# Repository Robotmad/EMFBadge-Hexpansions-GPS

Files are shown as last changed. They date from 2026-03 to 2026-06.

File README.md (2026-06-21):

# 📡 GPS Hexpansion for Tildagon Badge

A GPS Hexpansion module and basic software implementation for the Tildagon badge.

This project provides a working foundation for adding location awareness to badge applications — including hardware integration, UART communication, and NMEA parsing.

Designed for experimentation, hacking, and building more advanced location-based features.

They are available to buy here: https://themachineshop.uk/products/gps-hexpansion/

---

## ✨ Overview

This repository contains:

* ⚙️ Hardware files built in KiCAD
* 📡 UART-based communication with a GPS module
* 🧠 Basic NMEA parsing (RMC / GGA)
* 🖥️ Minimal software to extract and use position data
* 📷 Images of the board

It’s intended as a **starting point** for developing GPS-enabled badge apps.

---

## 🖼️ Hardware

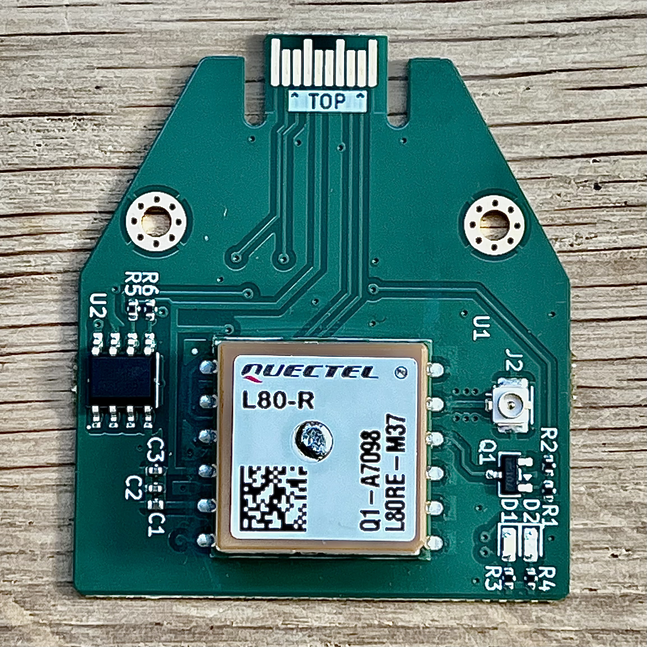
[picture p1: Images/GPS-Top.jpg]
GPS Hexpansion Top

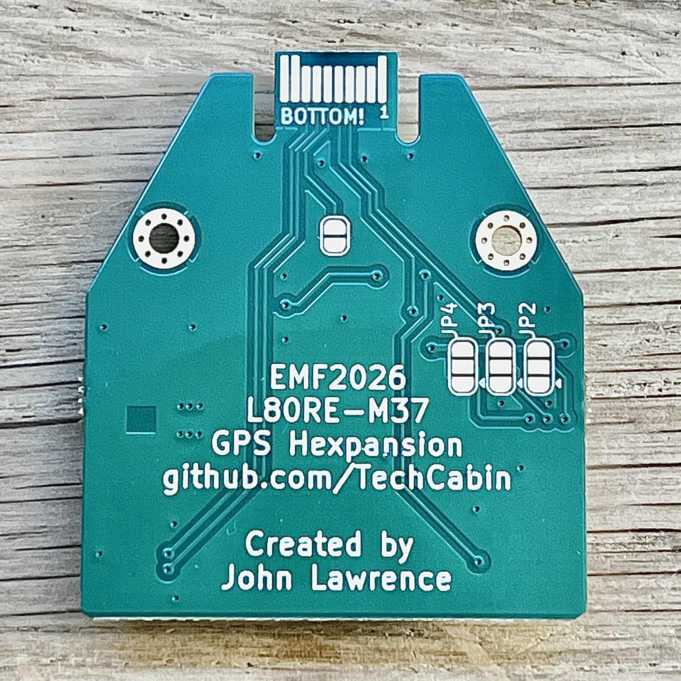
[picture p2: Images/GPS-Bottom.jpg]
GPS Hexpansion Bottom

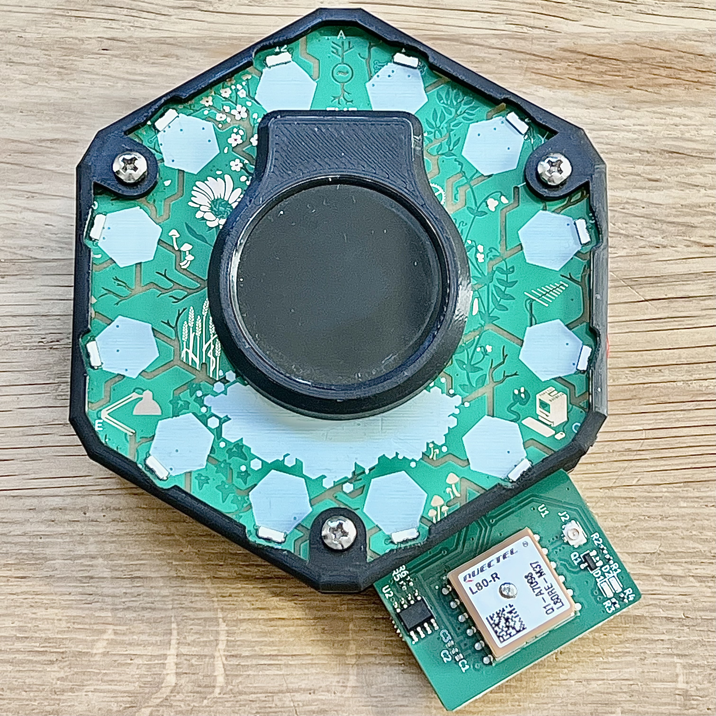
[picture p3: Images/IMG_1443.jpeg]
Badge with Hexpansion

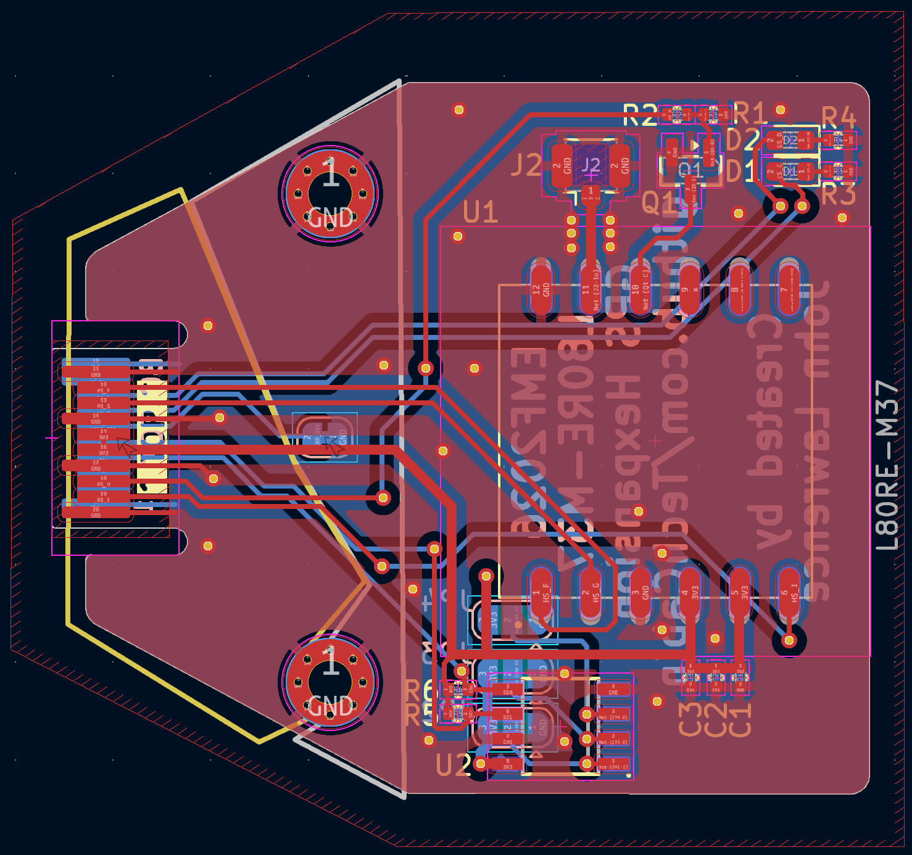
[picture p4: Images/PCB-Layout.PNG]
Hexpansion Layout

---

## 🔌 Hardware Details

* Compatible with the EMF2026 Tildagon Badge
* L80RE-M37 GPS module with built-in patch antenna
* External antenna connector with automatic switch over
* M24C16-RMN6TP EEPROM
* Red and Yellow LEDs

## ⚙️ Software

The software demonstrates:

* Reading serial data from the GPS module
* Parsing NMEA sentences (`$GNRMC`, `$GPGGA`)
* Extracting:

  * Latitude
  * Longitude
  * Fix status

This provides a clean base layer for any GPS-driven feature.

---

## 🧠 How It Works

1. GPS module outputs NMEA strings over UART
2. Badge reads serial stream
3. Valid sentences are identified
4. Data is parsed into usable values
5. Position data becomes available to your application
6. LED D1 is lit when there is a valid fix
---

## 🚀 Getting Started

```bash
git clone https://github.com/TechCabin/EMFBadge-Hexpansions-GPS.git
```

1. Flash MicroPython to your badge via mpremote
2. Copy project files to the device
3. Connect the GPS module via UART
4. Power on the badge
5. Wait for a valid GPS fix

---

## ⚠️ Notes

* Outdoor use significantly improves performance
* First fix can take 30–60 seconds (cold start)

---

## 🛣️ TODO

* [ ] Improve NMEA parser robustness
* [ ] Add support for additional sentence types
* [ ] Abstract GPS into a reusable module/class
* [ ] Add example applications (mapping, tracking, etc.)
* [ ] Add signal quality / satellite info

---

## 🔧 Future Ideas

* Real-time mapping
* Etch-a-Sktech app
* Geofencing features
* Time synchronisation from GPS
* Capture the Flag game
* Find a Friend app

---

## 🤝 Contributing

Contributions welcome — especially if you build something cool on top of this.

---

## 🙌 Acknowledgements

* EMF Camp
* Tildagon badge creators
* Open-source GPS/NMEA documentation

---

## 📜 License

MIT

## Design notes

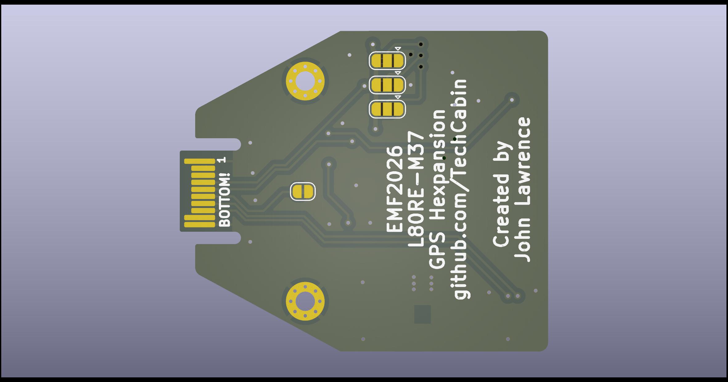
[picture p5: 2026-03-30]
Images/hexpansion-L80-5.jpg

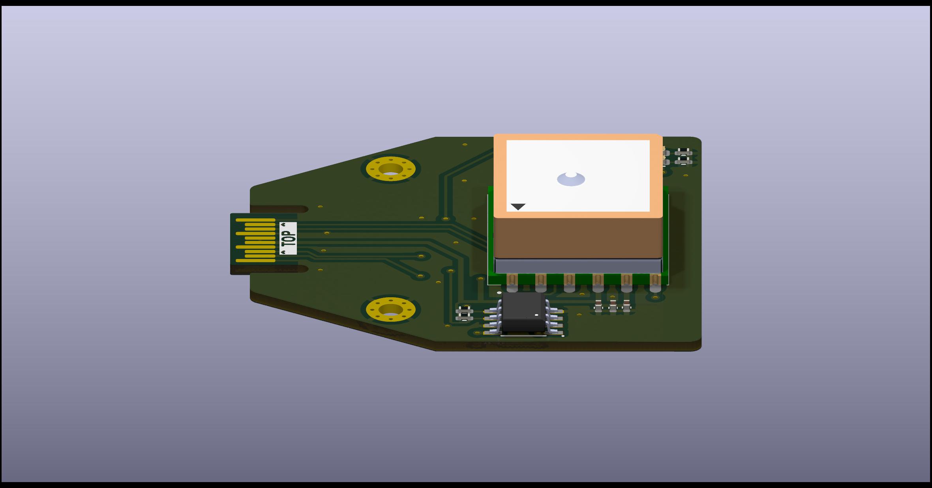
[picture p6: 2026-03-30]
Images/hexpansion-L80-2.jpg

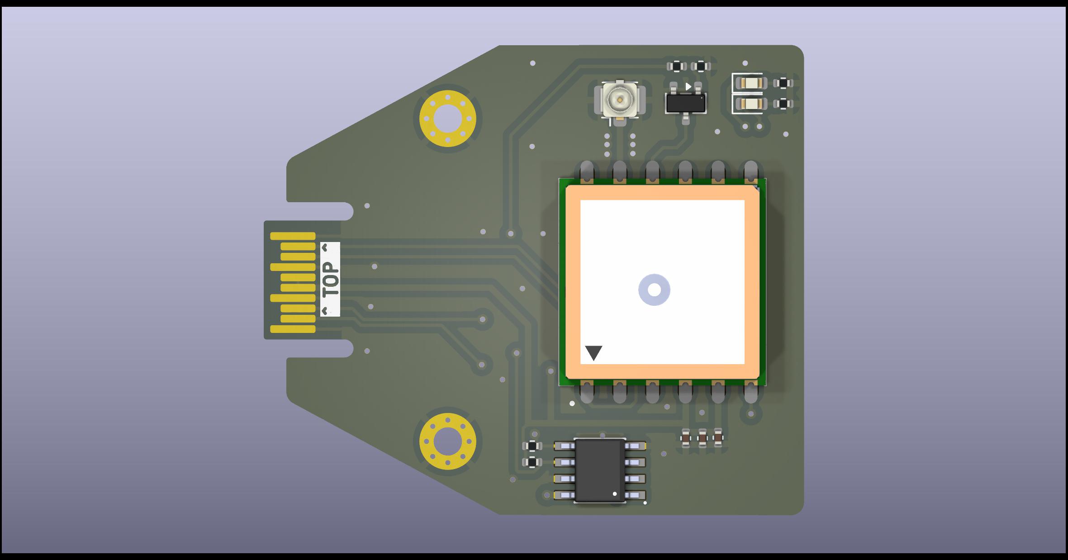
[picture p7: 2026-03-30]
Images/hexpansion-L80-1.jpg

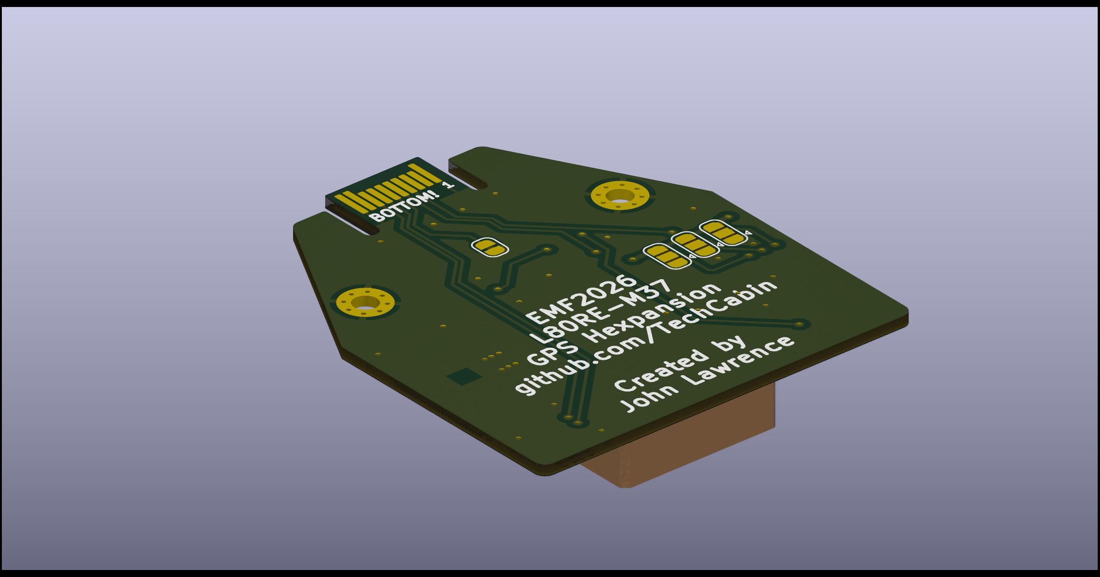
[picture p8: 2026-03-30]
Images/hexpansion-L80-7.jpg

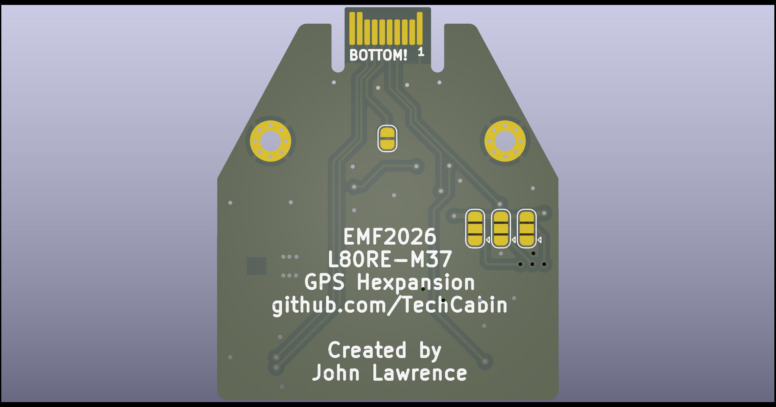
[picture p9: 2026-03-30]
Images/hexpansion-L80-6.jpg

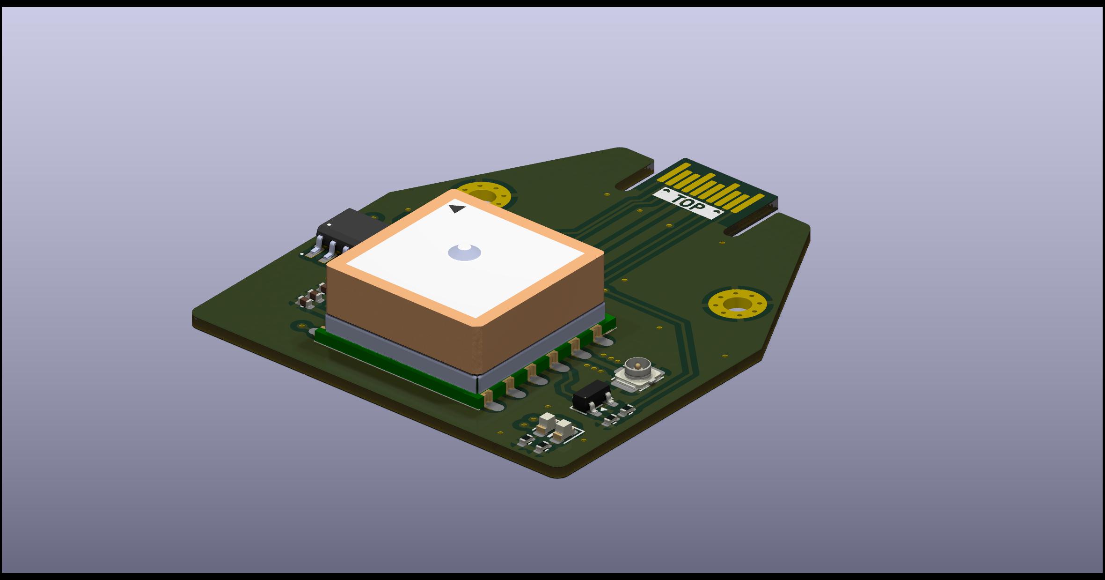
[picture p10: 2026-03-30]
Images/hexpansion-L80-4.jpg

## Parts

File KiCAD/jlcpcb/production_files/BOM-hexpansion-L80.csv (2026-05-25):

Comment | Designator | Footprint | LCSC | Quantity
100n | C2,C3 | C_0402_1005Metric | C1525 | 2
10u | C1 | C_0402_1005Metric | C15525 | 1
4.7K | R2,R3,R4,R5,R6 | R_0402_1005Metric | C25900 | 5
47K | R1 | R_0402_1005Metric | C25792 | 1
BC847 | Q1 | SOT-23 | C22446827 | 1
Conn_Coaxial | J2 | U.FL_Hirose_U.FL-R-SMT-1_Vertical | C5137195 | 1
L80RE-M37 | U1 | XCVR_L80RE-M37 | C3029061 | 1
M24C16-RMN6TP | U2 | SOIC127P600X175-8N | C79946 | 1
RED | D2 | LED_0603_1608Metric | C2286 | 1
WHITE | D1 | LED_0603_1608Metric | C2290 | 1

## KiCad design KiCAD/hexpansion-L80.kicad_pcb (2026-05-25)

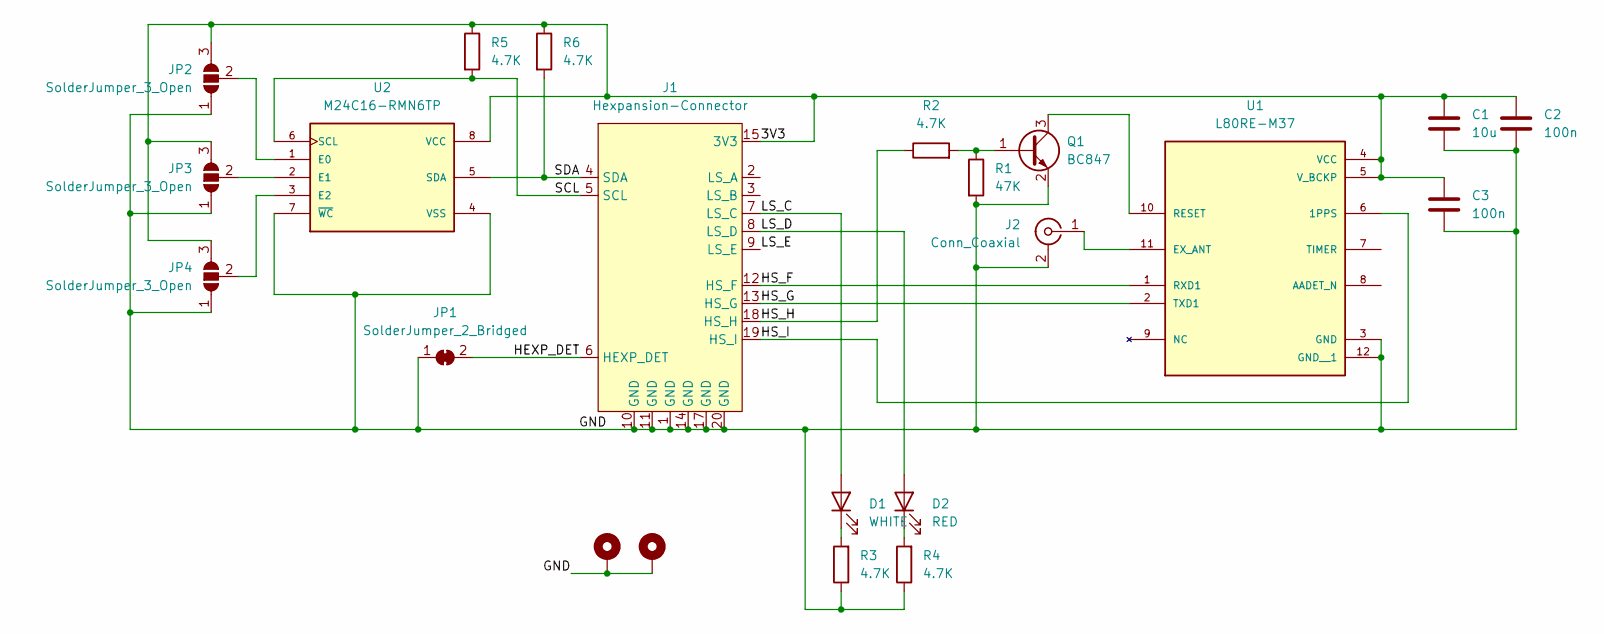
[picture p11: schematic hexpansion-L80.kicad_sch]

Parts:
C1: 10u; C_0402_1005Metric
C2, C3: 100n; C_0402_1005Metric
D1: WHITE; LED_0603_1608Metric
D2: RED; LED_0603_1608Metric
H1, H2: MountingHole_Pad; MountingHole_2.2mm_M2_Pad_Via
J1: Hexpansion-Connector; hexpansion-edge-connector
J2: Conn_Coaxial; U.FL_Hirose_U.FL-R-SMT-1_Vertical
JP1: SolderJumper_2_Bridged; SolderJumper-2_P1.3mm_Bridged_RoundedPad1.0x1.5mm
JP2, JP3, JP4: SolderJumper_3_Open
Q1: BC847; SOT-23
R1: 47K; R_0402_1005Metric
R2, R3, R4, R5, R6: 4.7K; R_0402_1005Metric
U1: L80RE-M37; XCVR_L80RE-M37; PARTREV v1.4
U2: M24C16-RMN6TP; SOIC127P600X175-8N

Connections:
/3V3: C1.1, C2.1, C3.1, J1.15 (3V3), J1.16 (3V3), JP2.3 (B), JP3.3 (B), JP4.3 (B), R5.1, R6.1, U1.4 (VCC), U1.5 (V_BCKP), U2.8 (VCC)
/GND: C1.2, C2.2, C3.2, H1.1, H2.1, J1.1 (GND), J1.10 (GND), J1.11 (GND), J1.14 (GND), J1.17 (GND), J1.20 (GND), J2.2 (Ext), JP1.1 (A), JP2.1 (A), JP3.1 (A), JP4.1 (A), Q1.2 (E), R1.2, R3.1, R4.1, U1.3 (GND), U1.12 (GND__1), U2.4 (VSS), U2.7 (~WC)
/HEXP_DET: J1.6 (HEXP_DET), JP1.2 (B)
/HS_F: J1.12 (HS_F), U1.1 (RXD1)
/HS_G: J1.13 (HS_G), U1.2 (TXD1)
/HS_H: J1.18 (HS_H), R2.1
/HS_I: J1.19 (HS_I), U1.6 (1PPS)
/LS_C: D1.2 (A), J1.7 (LS_C)
/LS_D: D2.2 (A), J1.8 (LS_D)
/LS_E: J1.9 (LS_E)
/SCL: J1.5 (SCL), R5.2, U2.6 (SCL)
/SDA: J1.4 (SDA), R6.2, U2.5 (SDA)
unnamed: D1.1 (K), R3.2
unnamed: D2.1 (K), R4.2
unnamed: J2.1 (In), U1.11 (EX_ANT)
unnamed: JP2.2 (C), U2.1 (E0)
unnamed: JP3.2 (C), U2.2 (E1)
unnamed: JP4.2 (C), U2.3 (E2)
unnamed: Q1.1 (B), R1.1, R2.2
unnamed: Q1.3 (C), U1.10 (RESET)

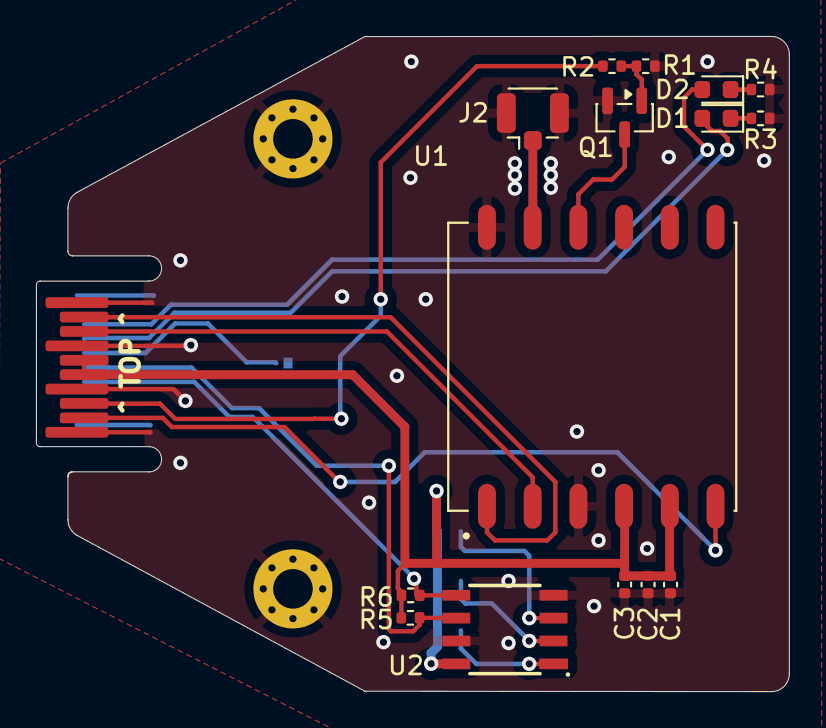
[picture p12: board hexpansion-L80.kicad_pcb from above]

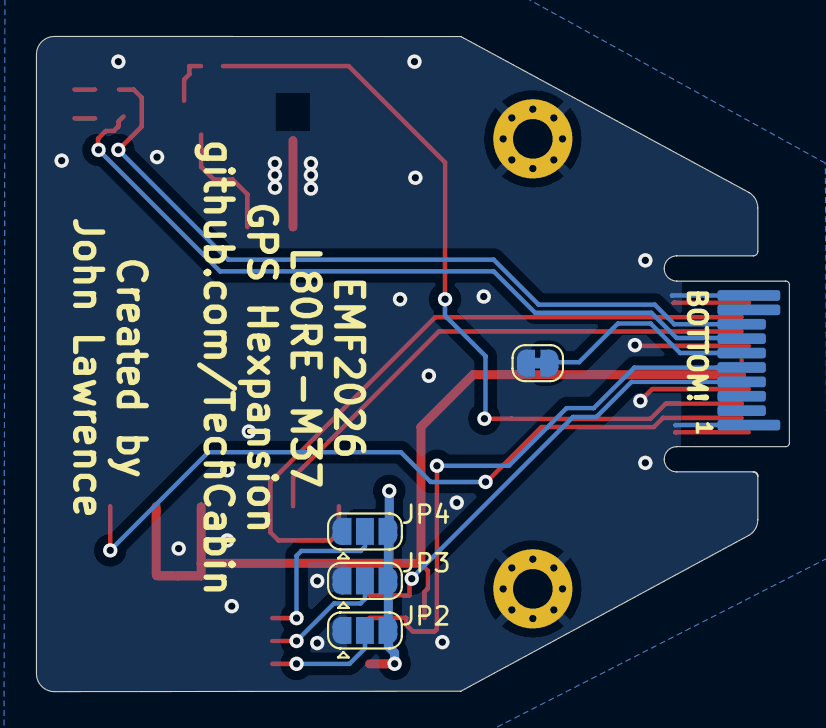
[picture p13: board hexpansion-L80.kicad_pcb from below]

Board: 2 copper layers, 41.8 x 36.4 mm, 22 parts (4 on the bottom side), 19 nets.

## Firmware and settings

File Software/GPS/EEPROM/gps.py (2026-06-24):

"""
GPS Hexpansion firmware (minimal) for the Tildagon badge.

Kept deliberately small to fit the tiny (2 KB) M24C16 EEPROM: it parses RMC for
position/speed/bearing (and emits the unchanged GPSEvent, so the emf-speedometer
app keeps working), and buffers the recent raw NMEA sentences so apps can parse
whatever else they need (GGA/GSV/GSA for altitude, satellite counts, sky maps)
themselves, on the badge where there is plenty of space.

checks for unused UART resource before using either UART1 or UART2

Based on the GPS firmware from https://github.com/mbooth101/emf-speedometer
License: MIT
"""
import app
import asyncio
import time

from events import Event
from system.eventbus import eventbus
from machine import UART, Pin, mem32
from micropython import const

# --- Pre-evaluated ESP32-S3 Hardware Registers & Masks ---
_CLK_REG   = const(0x600C0018)  # SYSTEM_PERIP_CLK_EN0_REG
_U1_BIT    = const(1 << 5)      # UART1 clock enable bit
_U2_BIT    = const(1 << 23)     # UART2 clock enable bit

class GPSApp(app.App):
    """Provides a GPS API for apps to use directly and GPS Events to subscribe to."""

    # Increment when the firmware changes in a way that needs a re-flash.
    VERSION = 1

    class GPSEvent(Event):
        def __init__(self, position, speed, bearing):
            self.position = position
            self.speed = speed
            self.bearing = bearing

        def __str__(self):
            return f"GPS fix {self.position}, speed {self.speed} knots, bearing {self.bearing}"

    def __init__(self, config=None):
        super().__init__()
        if config is None:
            raise TypeError
        self.config = config

        self._position = None
        self._bearing = 0
        self._speed = 0

        # Ring buffer of recent raw NMEA sentences (checksum stripped)
        self._lines = []

        self.to = 10
        self.uart = None
        u = 0

        # try to initialise UART 1 or 2 for GPS use
        # micropython is rather flawed and assumes that there is one 'thing' controlling use of the hardware
        # which it expects to manage which UARTs are used for what, hence if we ask for UART1 we get it regardless
        # of wheter it was already allocated to something else.  Unfortunately the hexpansion system
        # allows for many different hardware configurations so we can't always have UART1 (or even UART2)
        # Check if UART peripheral clock gating is enabled
        if not (mem32[_CLK_REG] & _U1_BIT):
            # no - so UART1 is available
            u = 1
        elif not (mem32[_CLK_REG] & _U2_BIT):
            # no - so UART2 is available
            u = 2
        if 0 < u:
            self.uart = UART(u, baudrate=9600, tx=config.pin[0], rx=config.pin[1], timeout=self.to)

        self.r = config.pin[2]
        self.r.init(mode=Pin.OUT)
        self.r.value(1)

        self.z = 0

    # Special function called by the BadgeOS to allow the app to clean up resources before it is removed from memory.
    # See https://github.com/emfcamp/badge-2024-software/pull/328
    def deinit(self):
        """release the UART."""
        if self.uart is not None:
            self.uart.deinit()

    @property
    def position(self):
        return self._position

    @property
    def bearing(self):
        return self._bearing

    @property
    def speed(self):
        return self._speed # round(self._speed, 2) - leave rounding to receiving app to save code space

    @property
    def sentences(self):
        """Recent raw NMEA sentences (checksum stripped) for apps to parse."""
        return list(self._lines)

    async def background_task(self):
        last = time.ticks_ms()
        while True:
            start = time.ticks_ms()
            delta = time.ticks_diff(start, last)
            result = self.background_update(delta)
            await asyncio.sleep_ms(25 if result else 250 - self.to)
            last = start

    def background_update(self, delta):
        self.z += delta

        if self.r.value():
            if self.z > 99:
                self.r.value(0)

        if self._position and self.z > 9999:
            self._position = None
            self._speed = 0
        try:
            l = self.uart.readline()        # moved inside try block as the least code to cope with potential that we don't actually have a uart
            if not l:
                return False
            line = l.decode().strip().split('*')[0]
            self._lines.append(line)
            if len(self._lines) > 40:
                self._lines = self._lines[-40:]

            p = line.split(',')
            if p[0][3:] == "RMC":
                if p[2] == "A":
                    lat = float(p[3][:2]) + float(p[3][2:]) / 60
                    lon = float(p[5][:3]) + float(p[5][3:]) / 60
                    if p[4] == "S":
                        lat = -lat
                    if p[6] == "W":
                        lon = -lon
                    self._position = (round(lat, 5), round(lon, 5))
                    self._speed = float(p[7]) if p[7] else 0.0
                    if p[8]:
                        self._bearing = float(p[8])
                    # Ignoring small speeds can be done in the application to save code space
                    # #if self._speed < 1:
                    #    self._speed = 0
                    self.z = 0
                eventbus.emit(self.GPSEvent(self._position, self._speed, self._bearing))
        except: # removed to save code space (UnicodeError, ValueError, AttributeError, IndexError):
            pass
        return True

__app_export__ = GPSApp # pylint: disable=invalid-name

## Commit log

2026-03-30 initial upload
    [10114830-10108LF.step, BOM-hexpansion-L80.csv, L80RE-M37.step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]
2026-04-07 Adding images of finished board
2026-05-03 Swap TX and RX pin definitions for GPS module
2026-05-25 rotated LEDs, fixed footprint sizing and regenerated production files
    [BOM-hexpansion-L80.csv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]
2026-05-25 rotated LEDs, fixed footprint sizing and rebuilt production files
2026-06-21 D1 indicates when fix is valid
    Initialise LS pin for D1 and set it active (high) when there is a valid fix.
    support deinit() function to tidy up use of resources when hexpansion removed as per https://github.com/emfcamp/badge-2024-software/pull/328
    [gps.py]
2026-06-21 Update README with LED indicator and TODO changes
    Added note about LED D1 indicating a valid fix and removed a TODO item regarding auto-detection of hexpansion port.
2026-06-24 check availability of UART resource
